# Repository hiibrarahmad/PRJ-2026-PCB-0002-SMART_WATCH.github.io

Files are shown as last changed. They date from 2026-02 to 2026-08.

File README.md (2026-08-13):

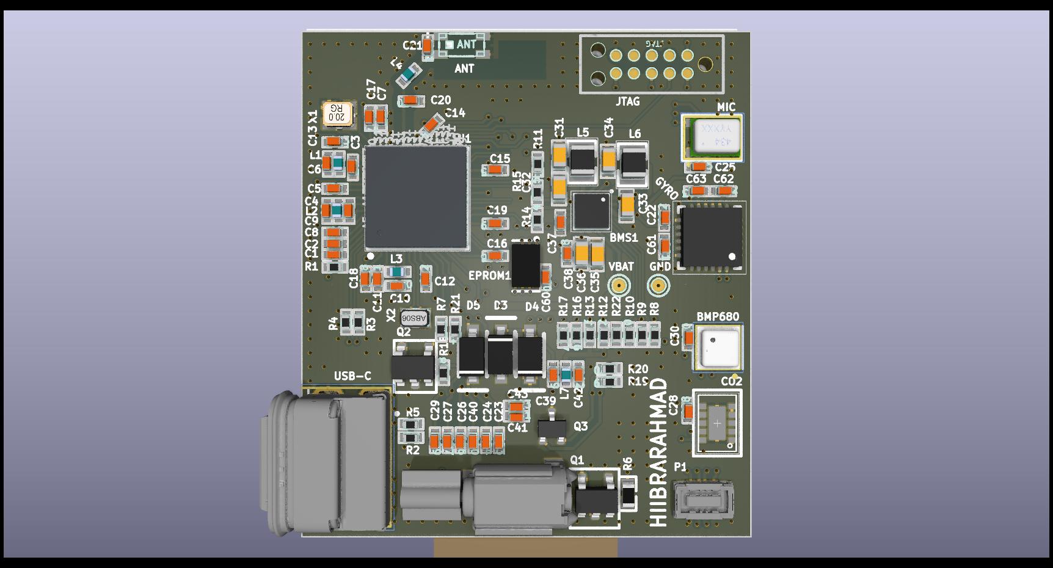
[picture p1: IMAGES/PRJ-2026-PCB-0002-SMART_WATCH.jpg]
Main Board Top


# ⚡ PRJ-PCB-1005-2024-SmartWatch
### Dual-Board Smart Watch PCB — Main Board & Wireless Charging Board
**Designed by hiibrarahmad · Powered by nRF5340 SoC**












[🔬 Interactive PCB View](https://hiibrarahmad.github.io/PRJ-PCB-1005-2024-SmartWatch.github.io/) · [📋 Project Assets](https://github.com/hiibrarahmad/PRJ-PCB-1005-2024-SmartWatch.github.io/tree/main/IMAGES) · [📦 3D Model — Charger Board (STEP)](assets/SensCharger.step)

> [!NOTE]
> A real 3D model exists for the **Charger Board** only (`assets/SensCharger.step`, exported from the source design). No STEP export exists yet for the Main Board.

---

## 📖 Project Overview

**PRJ-PCB-1005-2024-SmartWatch** is a **compact dual-board smart watch platform** featuring a main application board with a color IPS/e-Paper display and a dedicated wireless charging board with Qi inductive charging support. Designed around the **Nordic Semiconductor nRF5340** dual-core SoC, this wearable platform integrates Bluetooth 5.3, health sensing (PPG + SpO2 + ECG), environmental monitoring, CO₂ sensing, and a full IMU — all packed into a wristwatch form factor.

> 💡 The **Main Board** hosts the nRF5340 SoC and all application peripherals including display, sensors, and connectivity. The **Charger Board** provides wireless Qi charging reception via BQ51003, battery management via BQ25100, and PPG/SpO2 sensing via MAX86150.

---

## 🖼️ PCB Preview

| 🔝 Top Side | 🔻 Bottom Side |
|---|---|
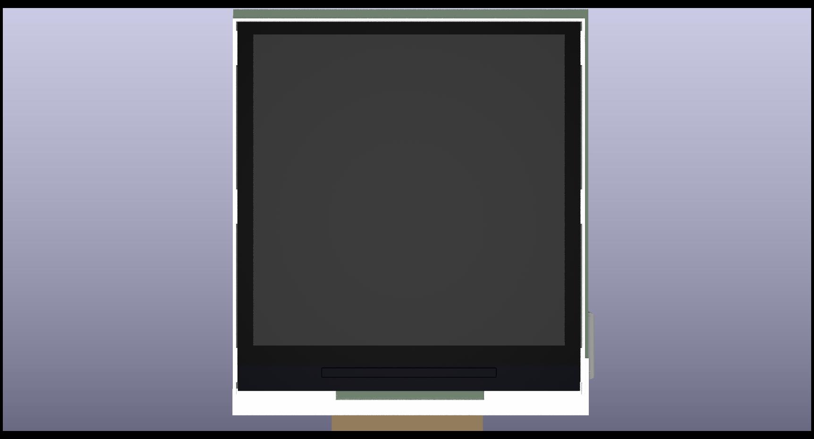
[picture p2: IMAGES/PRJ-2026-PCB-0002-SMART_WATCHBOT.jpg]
Main Board Bottom
|   | Main Board Top |

### 🔋 Charger Board — Top & Bottom

| 🔝 Top Side | 🔻 Bottom Side |
|---|---|
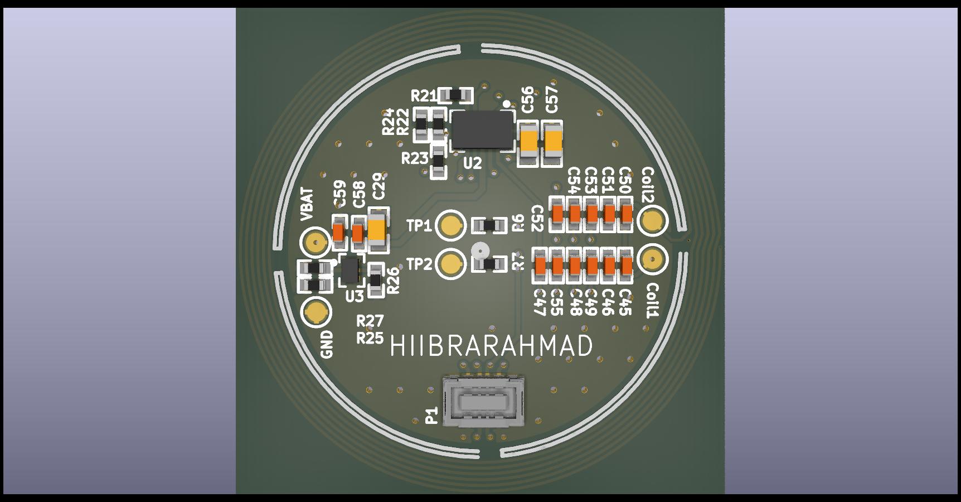
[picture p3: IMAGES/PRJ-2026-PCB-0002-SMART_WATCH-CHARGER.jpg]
Charger Top
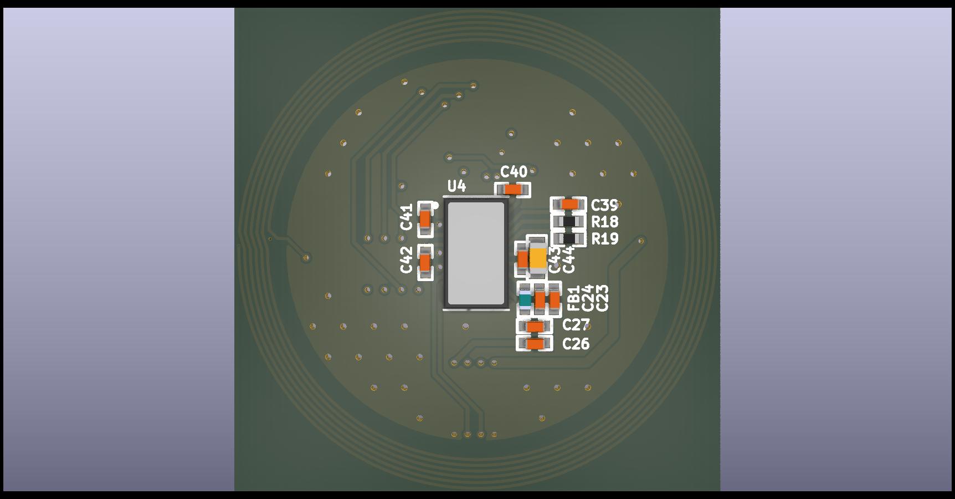
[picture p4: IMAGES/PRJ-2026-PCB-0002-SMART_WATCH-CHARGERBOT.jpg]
Charger Bottom
|  |  |

🔗 **[→ View Interactive PCB Online](https://hiibrarahmad.github.io/PRJ-PCB-1005-2024-SmartWatch.github.io/)**

---

## 🎯 Core Design Goals

| Goal | Specification |
|---|---|
| ⌚ **Wearable Form Factor** | Ultra-compact dual-board stack for wristwatch enclosure |
| 🖥️ **Dual Display Support** | 1.54" IPS Color LCD + 1.54" e-Paper (low-power mode) |
| 📡 **Wireless Connectivity** | Bluetooth 5.3 (nRF5340), 2.4 GHz antenna |
| 🔋 **Wireless Charging** | Qi inductive charging via BQ51003 receiver |
| 💓 **Health Sensing** | PPG, SpO2, ECG via MAX86150 |
| 🌡️ **Environmental Sensing** | Temperature, Humidity, Pressure, Gas (BME680) |
| 💨 **Air Quality** | CO₂ / eCO₂ / TVOC sensing via CCS811 |
| 🏃 **Motion Sensing** | 6-axis IMU via ICM-20689 |
| 🔒 **Security** | ARM TrustZone on Cortex-M33, Secure Boot |

---

## 💻 nRF5340 SoC — Main Processor

This board is built around the **Nordic Semiconductor nRF5340** — the world's first dual-core Bluetooth 5.3 SoC for advanced wearable applications.

| Category | Specification |
|---|---|
| 🧮 **Application Core** | ARM® Cortex®-M33 @ 128 MHz, TrustZone, FPU, DSP |
| 🌐 **Network Core** | ARM® Cortex®-M33 @ 64 MHz (dedicated BLE/radio control) |
| 💾 **Flash** | 1 MB (App) + 256 KB (Net) |
| 🗃️ **RAM** | 512 KB (App) + 256 KB (Net) |
| 📡 **Bluetooth** | BT 5.3 LE, Long Range, Bluetooth Mesh, Direction Finding |
| 🔐 **Security** | ARM TrustZone, Secure Boot, CryptoCell-312, ARM PSA Level 2 |
| 🔌 **USB** | Full Speed USB 2.0 with integrated PHY |
| 📟 **Serial I/O** | 4× UARTE · 5× SPI/I2C · I2S · PDM · 32× GPIO |
| ⚡ **Operating Voltage** | 1.7V – 5.5V |
| 📐 **Package** | QKA (7×7 mm, 94-pin AQFN) |
| 🌡️ **Operating Temp** | −40°C to +85°C |

---

## 🔌 PCB Interface Map

### 🖥️ Display Interfaces
- **SPI** → 1.54" IPS TFT Color LCD (ER-TFT1.54-1) — always-on mode
- **SPI** → 1.54" e-Paper Display (GDEW0154T8DE) — ultra-low-power ambient mode
- Dedicated SPI bus with chip selects for each display

### 💓 Health & Bio-Sensing
- **I2C** → MAX86150 (PPG, SpO2, ECG analog front-end) on Charger Board
- Optical heart rate monitoring
- Single-lead ECG acquisition

### 🌡️ Environmental Sensing
- **I2C** → BME680 (Temperature · Humidity · Barometric Pressure · Gas/VOC)
- **I2C** → CCS811 (eCO₂ and TVOC Air Quality Sensor)

### 🏃 Motion & Audio
- **SPI** → ICM-20689 (6-DoF IMU: 3-axis Gyroscope + 3-axis Accelerometer)
- **PDM** → ICS-43432 Digital MEMS Microphone

### 🔋 Power & Charging System
- **Qi Wireless Charging** via BQ51003 receiver IC (Charger Board)
- **Battery Management** via BQ25100 Li-Ion charger (Charger Board)
- VBAT battery rail with test points
- Coil1 / Coil2 wireless coil interface pads
- BLM15AX102SN1D EMI Ferrite Bead Filter on power rail

### 💾 Storage
- **SPI** → M95512-A125 (512 Kbit / 64 KB SPI EEPROM)

### 🔗 Connectivity & Debug
- **USB-C** → 2305018-2 connector (USB Full Speed, charging & data)
- **SWD/JTAG** → FTSH-105-01-F-DV-K-TR debug header (2×5, 1.27 mm)
- **RF** → 2450AT18D0100 2.4 GHz chip antenna
- **GPIO** → Board-to-board connector (P1, 50500408125)

### ⏱️ Clocking
- **X1** → 32 MHz crystal (2016 package) — Primary RF and CPU clock
- **X2** → 32.768 kHz crystal (2012 package) — RTC and low-power sleep clock

---

## 📋 Bill of Materials Summary

### 🟦 Main Board (PRJ-PCB-1005-2024-SmartWatch)

| Category | Key Components | Qty |
|---|---|-----|
| 🧠 **MCU** | nRF5340-QKA (Nordic) | 1 |
| 🖥️ **Display** | ER-TFT1.54-1 (1.54" IPS) + GDEW0154T8DE (1.54" e-Paper) | 2 |
| 📡 **RF Antenna** | 2450AT18D0100 (2.4 GHz chip antenna) | 1 |
| 🏃 **IMU** | ICM-20689 (6-axis, QFN) | 1 |
| 🌡️ **Env. Sensor** | BME680 (Temp/Hum/Press/Gas) | 1 |
| 💨 **Air Quality** | CCS811B-JOPR (CO₂/TVOC) | 1 |
| 🎙️ **Microphone** | ICS-43432 (Digital PDM MEMS) | 1 |
| 💾 **EEPROM** | M95512-A125 (512 Kbit SPI) | 1 |
| 🔌 **USB-C** | 2305018-2 Connector | 1 |
| 🔧 **Debug** | FTSH-105-01-F-DV-K-TR (SWD/JTAG) | 1 |
| 🔮 **MOSFET** | BC816-25HV + Si1308EDL (SOT23/SOT323) | 3 |
| ⏱️ **Crystals** | 32 MHz (X1) + 32.768 kHz (X2) | 2 |
| ⚡ **Diodes** | MBR0530 Schottky (SOD-123) | 3 |
| 📦 **Passives** | Resistors, Capacitors (0402/0603), Inductors | ~65 |

### 🟧 Charger Board (PRJ-PCB-1005-2024-SmartWatch-Charger)

| Category | Key Components | Qty |
|---|---|-----|
| 🔋 **Wireless Rx** | BQ51003YFPR (Qi receiver IC) | 1 |
| ⚡ **Battery Charger** | BQ25100YFPT (Li-Ion charger) | 1 |
| 💓 **Health Sensor** | MAX86150EFF+ (PPG/SpO2/ECG AFE) | 1 |
| 🔌 **Board Connector** | P1 50500408125 | 1 |
| 🔧 **EMI Filter** | BLM15AX102SN1D (Ferrite Bead) | 1 |
| 📦 **Passives** | Resistors, Capacitors (0402/0603) | ~35 |

---

## 📐 PCB Specifications

### Main Board

| Parameter | Value |
|---|---|
| PCB Definition | Main Application Board |
| Layer Count | 4 Layers |
| Material | FR4 |
| Surface Finish | Immersion Gold (ENIG) |
| Solder Mask | Top & Bottom · Color: Green |
| Silkscreen | Top & Bottom · Color: White |
| Impedance Control | ✅ Yes |
| RoHS | ✅ Compliant |

### Charger Board

| Parameter | Value |
|---|---|
| PCB Definition | Wireless Charging Board |
| Layer Count | 4 Layers |
| Material | FR4 |
| Surface Finish | Immersion Gold (ENIG) |
| Solder Mask | Top & Bottom · Color: Green |
| Silkscreen | Top & Bottom · Color: White |
| Impedance Control | ✅ Yes |
| RoHS | ✅ Compliant |

---

## 🧱 PCB Stack-Up

```
┌─────────────────────────────────────────┐
│  TOP LAYER     │  CU     │ 0.035 mm (1.4 mil)  │
├─────────────────────────────────────────┤
│  PREPREG       │         │ 0.066 mm (2.6 mil)  │
├─────────────────────────────────────────┤
│  LAYER 1       │  CU     │ 0.035 mm (1.4 mil)  │  ← GND Reference
├─────────────────────────────────────────┤
│  PREPREG       │         │ 1.27 mm  (50 mil)   │  ← CORE
├─────────────────────────────────────────┤
│  LAYER 2       │  CU     │ 0.035 mm (1.4 mil)  │  ← Power / GND
├─────────────────────────────────────────┤
│  PREPREG       │         │ 0.066 mm (2.6 mil)  │
├─────────────────────────────────────────┤
│  BOTTOM LAYER  │  CU     │ 0.035 mm (1.4 mil)  │
└─────────────────────────────────────────┘
```

---

## 📏 Impedance Control Reference

| Target Impedance | Layer | Trace Width / Gap |
|---|---|---|
| 50 Ω ±10% | TOP LAYER | 4 mil (single-ended RF) |
| 50 Ω ±10% | BOTTOM LAYER | 4 mil (single-ended) |
| 90 Ω ±10% | TOP LAYER | 4.495 mil / 4 mil (USB diff pair) |
| 90 Ω ±10% | BOTTOM LAYER | 4.495 mil / 4 mil |

> ⚠️ All high-speed signals (USB Full Speed, SPI @ >10 MHz, RF traces) are impedance-controlled. Reference layers: **TOP → Layer 1**, **BOTTOM → Layer 2**. RF trace from nRF5340 to antenna must be routed as 50 Ω microstrip.

---

## ⌚ Smart Watch — Feature Requirements

The dual-board platform is designed to fulfill the following product-level requirements:

- ✅ Compact wristwatch form factor — dual stacked PCB design
- ✅ Dual display: color IPS LCD for active use + e-Paper for ambient/always-on
- ✅ Bluetooth 5.3 wireless connectivity (nRF5340)
- ✅ Wireless Qi charging via dedicated charger board
- ✅ Li-Ion battery management with USB-C fallback charging
- ✅ Optical heart rate, SpO2, and ECG health monitoring
- ✅ Environmental monitoring: temperature, humidity, pressure, gas
- ✅ CO₂ and air quality monitoring (CCS811)
- ✅ 6-axis motion sensing for step counting, gesture, and activity tracking
- ✅ Digital MEMS microphone for voice interaction
- ✅ ARM TrustZone security for health data protection
- ✅ OTA firmware update via Bluetooth (Nordic DFU)
- ✅ SWD/JTAG debug interface for development

---

## 🛠️ Software & Firmware

| Component | Details |
|---|---|
| **RTOS** | Zephyr RTOS (Nordic SDK) |
| **BLE Stack** | SoftDevice / BLE 5.3 (nRF5340 Network Core) |
| **SDK** | nRF Connect SDK (NCS) |
| **Bootloader** | MCUboot (Secure OTA) |
| **Security** | TF-M (Trusted Firmware-M), ARM PSA Level 2 |
| **Health APIs** | PPG/SpO2/ECG via MAX86150 driver |
| **Sensor Drivers** | BME680, CCS811, ICM-20689 Zephyr drivers |
| **Display Stack** | LVGL (GUI framework for wearable UI) |
| **BLE Profiles** | HRS, HTS, DIS, BAS, Custom Health Service |
| **OTA Updates** | Nordic DFU over BLE |

---

## 📁 Repository Structure

```
PRJ-PCB-1005-2024-SmartWatch.github.io/
│
├── IMAGES/
│   ├── PRJ-2026-PCB-0002-SMART_WATCH.jpg          ← Main Board Top (JPG)
│   ├── PRJ-2026-PCB-0002-SMART_WATCHBOT.jpg       ← Main Board Bottom (JPG)
│   ├── PRJ-2026-PCB-0002-SMART_WATCH-CHARGER.jpg  ← Charger Board Top (JPG)
│   └── PRJ-2026-PCB-0002-SMART_WATCH-CHARGERBOT.jpg ← Charger Board Bottom (JPG)
│
├── index.html      ← Board picker (Main Board / Wireless Charger Board)
├── main.html       ← Main board interactive PCB/BOM viewer
├── charger.html    ← Wireless charger board interactive PCB/BOM viewer
└── README.md       ← This file
```

---

## 🔗 Links

| Resource | URL |
|---|-----|
| 🌐 **Interactive PCB View** | [hiibrarahmad.github.io/PRJ-PCB-1005-2024-SmartWatch.github.io](https://hiibrarahmad.github.io/PRJ-PCB-1005-2024-SmartWatch.github.io/) |
| 📦 **nRF5340 SoC** | [Nordic Semiconductor nRF5340](https://www.nordicsemi.com/products/nrf5340) |
| 📝 **nRF Connect SDK** | [developer.nordicsemi.com](https://developer.nordicsemi.com) |
| 📜 **License** | Proprietary — © 2026 hiibrarahmad. All Rights Reserved. |

---

<div align="center">

**PRJ-PCB-1005-2024-SmartWatch**

*Dual-Board Smart Watch Platform · Main Board + Wireless Charger Board*





© 2026 hiibrarahmad. All Rights Reserved.

</div>

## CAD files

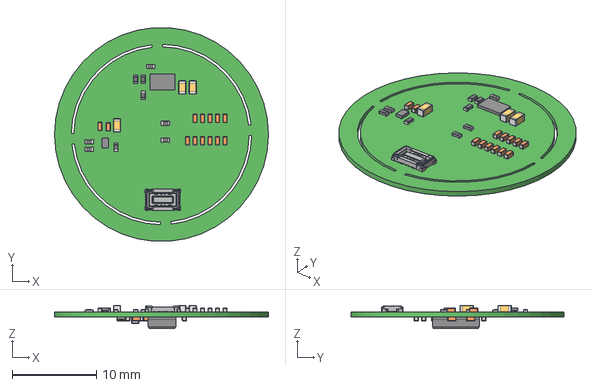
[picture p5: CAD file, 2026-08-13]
assets/SensCharger.step
25.4 x 25.3 x 2.75 mm

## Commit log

2026-08-13 Restructure showcase, flatten layout, drop unused Step File viewer
    The menu had three options: Main Board, Wireless Board (both real
    InteractiveHtmlBom viewers) and Step File — the latter pulling in a
    vendored js-3d-model-viewer library plus ~150MB of generic demo assets
    (avocado/duck/helmet/sneakers sample models) with no real Smart Watch
    3D model behind them at all. Removed the Step File option and the
    entire vendored library/build tooling. Flattened src/main.html and
    src/src/Charger.html to root (main.html, charger.html), moved
    src/IMAGES to IMAGES/. Fixed both viewers' embedded BOM titles, fixed
    repo-path links in README (image filenames left as-is), removed the
    misattributed LICENSE r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
    [sample_03.obj]
2026-08-13 Fix year references after rename (2026->2024), add real Charger STEP model
    Repo was renamed twice in one session (first to match its own creation
    date, then corrected to match the paired source repo's earlier 2024
    creation date for consistency). Also adds the real Charger board STEP
    model (copied from the private source repo) for the portfolio's 3D viewer.
    [SensCharger.step]
